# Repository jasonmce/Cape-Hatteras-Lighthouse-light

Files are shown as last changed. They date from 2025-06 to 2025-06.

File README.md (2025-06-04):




# 🗼 Cape Hatteras Lighthouse Light

This project recreates the iconic Cape Hatteras Lighthouse light as a 3D-printed model, complete with an Arduino-driven animation that mimics the real-world light signature of the actual lighthouse. At dusk a string of NeoPixels illuminate the lighthouse with a rotating beam effect - to help my sister park &#128515;.

It is an example of a solar-powered Lighthouse Light, with a weatherproof enclosure, a switch to turn it on and off, and a solar charge controller to keep the battery charged.  It is meant to be easy to extend for creating your own lighthouse light model and custom signature.

## 📚 Background
My sister asked for a Cape Hatteras lighthouse garden decoration for her birthday.  Making the body was a fun project, but illuminating it was the part that interested me.  It was a great experience in what could go wrong with distantly deployed deliverables.

Evolutions in this project:
- Upgraded to a **10K mAh battery** to survive multiple days of darkness
- Stronger housing.  I originally used [Thingiverse myst lighthouse](https://www.thingiverse.com/thing:3164021) as the light fixture but it proved brittle when:
    - branches hit it
    - wind toppled the structure
- Designed a custom light model to better match the Cape Hatteras light
- Added an external power switch to:
    - Reset the circuit if low voltage causes Arduino issues
    - Ensure a solid charge after prolonged darkness
---

## 🔧 Features

- Fully 3D printable model, designed in modular STL components.
- Arduino-compatible `.ino` sketch to drive a NeoPixel LED strip.
- Solar powered - no charging or replacing of batteries required.
- Detects when it is dark and animates the light.
- Mimics the actual flash pattern of Cape Hatteras Lighthouse (light every 7.5 seconds).
- Designed to house internal wiring and switch access.
  
---

## 🖨️ 3D Printed Parts

All STL files can be found [On Thingiverse](https://www.thingiverse.com/thing:7056934) and in the `models/` directory:

- `roof.stl` – Top cap for the lighthouse.
- `lens.stl` – Translucent lens for the light animation.
- `base.stl` – Base of the lighthouse.
- `base_ring_for_switch.stl` – Fits below base to allow switch access.
- `core.stl` – Internal lighthouse column that holds electronics.

---

## 🧠 Arduino Code

The `code/lighthouse.ino` sketch uses the Adafruit NeoPixel library to animate a light strip. It creates a rotating beam with fade transitions that align with the lighthouse's characteristic 7.5-second interval signature.

Requirements:
- Arduino Uno or compatible board - I used a Seeeduino XIAO because it was handy.
- Adafruit NeoPixel library
- 21 NeoPixel strip - can be customized to any length
- Light sensor
- Solar panel
- Weather proof switch
- Solar charge controller
- LiPo battery - Mine is a whopping 10K mAh to outlast a few dark or rainy days

---

## 🖼️ Photos

<figure>
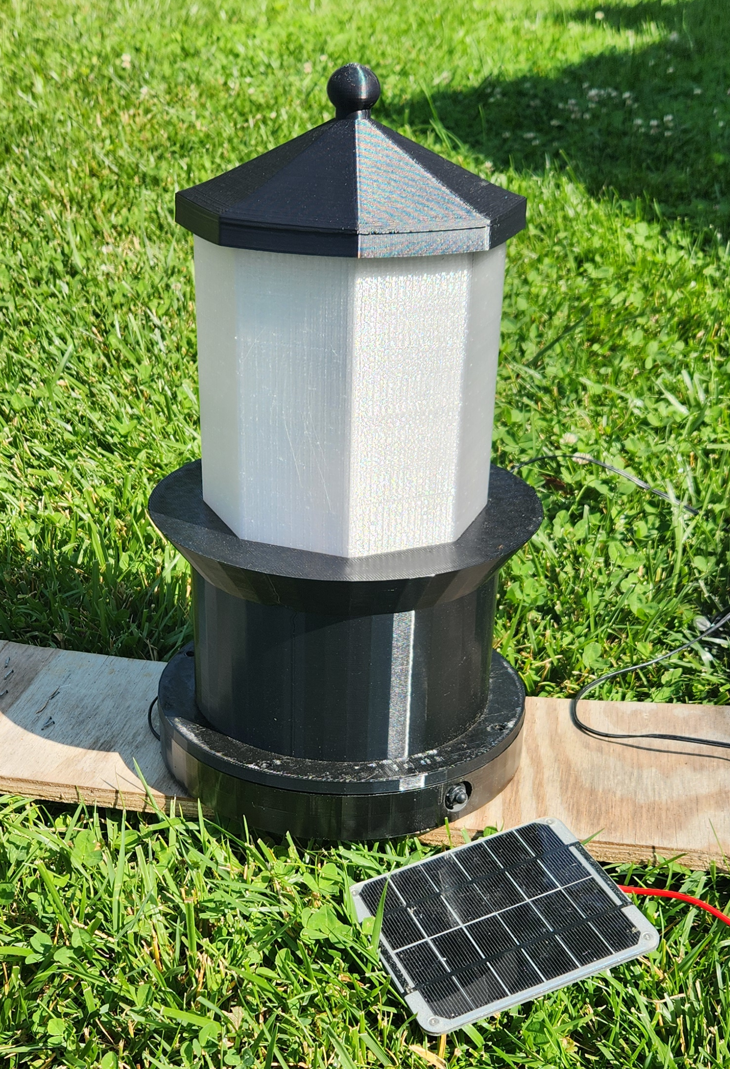
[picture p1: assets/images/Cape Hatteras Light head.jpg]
Assembled lighthouse with solar panel
    
    <figcaption><strong>Model Head</strong></figcaption>
</figure>
<figure>
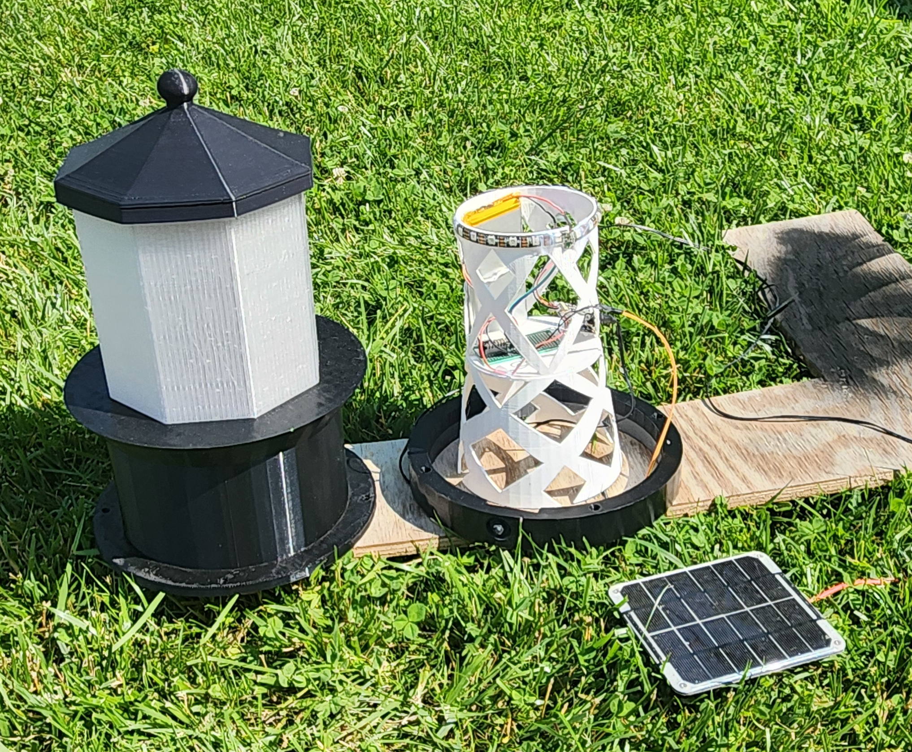
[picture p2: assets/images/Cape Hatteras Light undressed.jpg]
Lighthouse with electronics exposed
    
    <figcaption><strong>Undressed View</strong></figcaption>
</figure>
<figure>
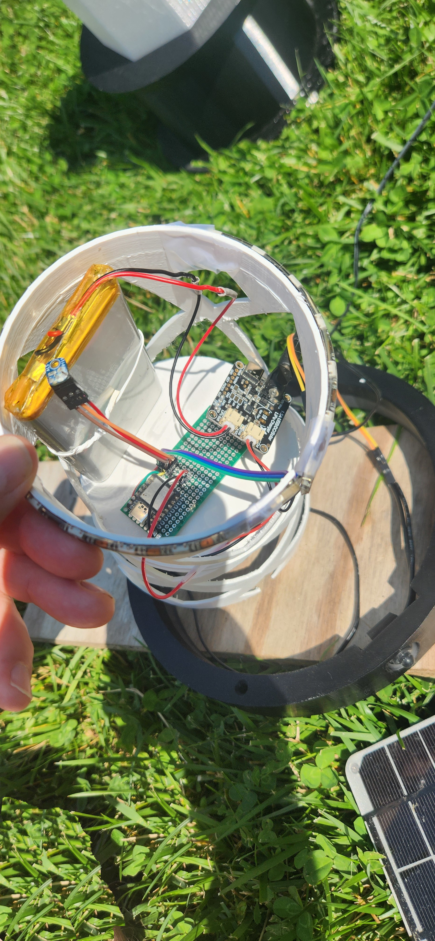
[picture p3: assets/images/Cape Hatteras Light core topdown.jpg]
Top down view of the core electronics
    
    <figcaption><strong>Core Top-down View</strong></figcaption>
</figure>

---

## ⚙️ Assembly Notes

- Print the lens using clear or translucent filament for best light diffusion.
- Attach the NeoPixel strip onto the core, aligned with the center of the lens.
- Connect the NeoPixel strip to 5V, GND, and a digital pin (e.g., D10) on your Arduino.
- Connect the light sensor to an analog pin (e.g., A9) on your Arduino.
- Use the `base_ring_for_switch.stl` if you want external access to the power or mode switch
    It will control the connection between the solar controller output and the Arduino.

---

## 🔧 Future Enhancements

The following features are under consideration to improve usability, reliability, and functionality:

- **Adjustable Darkness Threshold**  
  Integrate a rheostat to allow users to fine-tune the ambient light threshold that triggers the lighthouse light. This would offer greater flexibility across varying environments and seasons.

- **Improved NeoPixel Strip Mounting**  
  Add structural clips around the top of the core to provide secure, mechanical support for the NeoPixel strip. This will improve long-term durability and reduce dependence on adhesive backing.

- **Inspection Mode via Wi-Fi Access Point**  
  Introduce an "Inspection" button that temporarily enables a local Wi-Fi Access Point. When connected, users would be presented with an HTML interface displaying real-time sensor values, status indicators, and system diagnostics for troubleshooting and fine-tuning.
---

## 📜 License

MIT License. Use and remix freely, and credit is appreciated.

---

## 🗺️ About the Real Lighthouse

Cape Hatteras Lighthouse is located in North Carolina and is known for its distinct black-and-white spiral pattern and strong maritime heritage. The animation in this project replicates its 7.5-second rotating flash pattern.

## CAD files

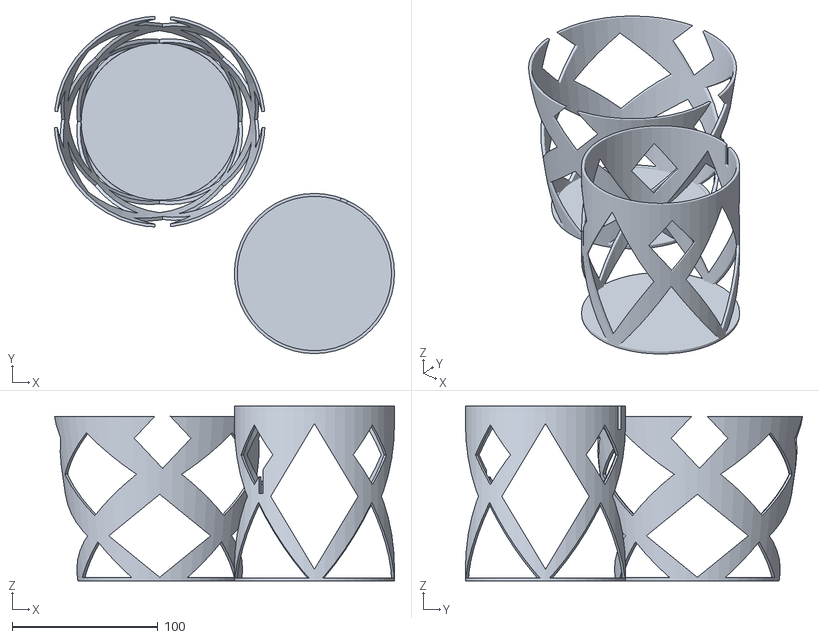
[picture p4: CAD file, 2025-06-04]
models/Cape Hatteras Light core.stl
233.5 x 231.6 x 120.0

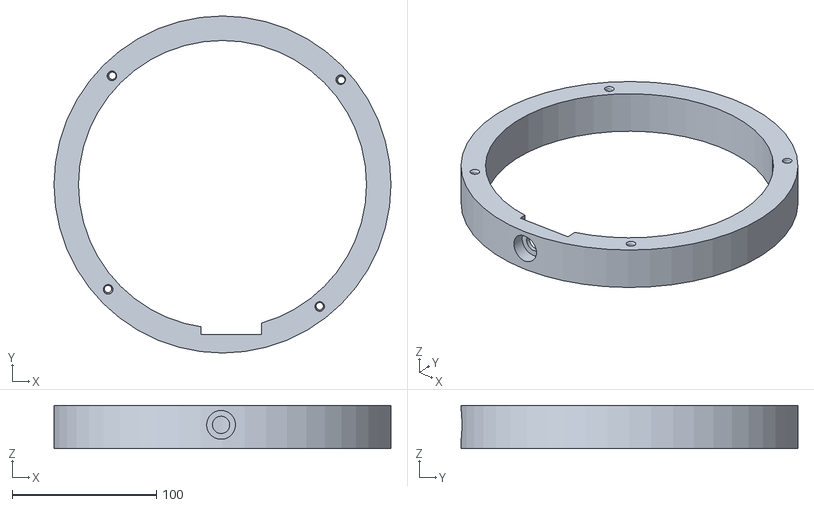
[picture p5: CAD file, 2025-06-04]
models/Cape Hatteras Light base ring for switch.stl
234.0 x 234.0 x 30.0

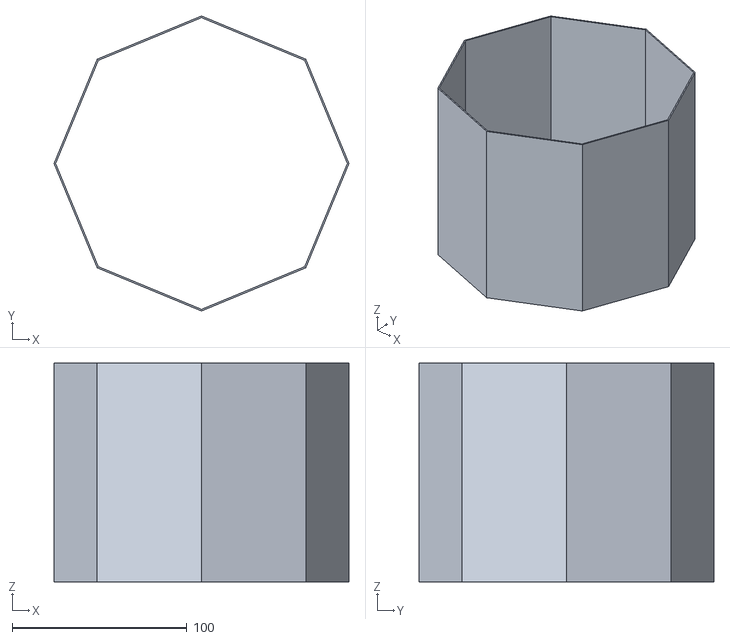
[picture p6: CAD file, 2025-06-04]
models/Cape Hatteras Light lens.stl
168.8 x 168.8 x 125.0

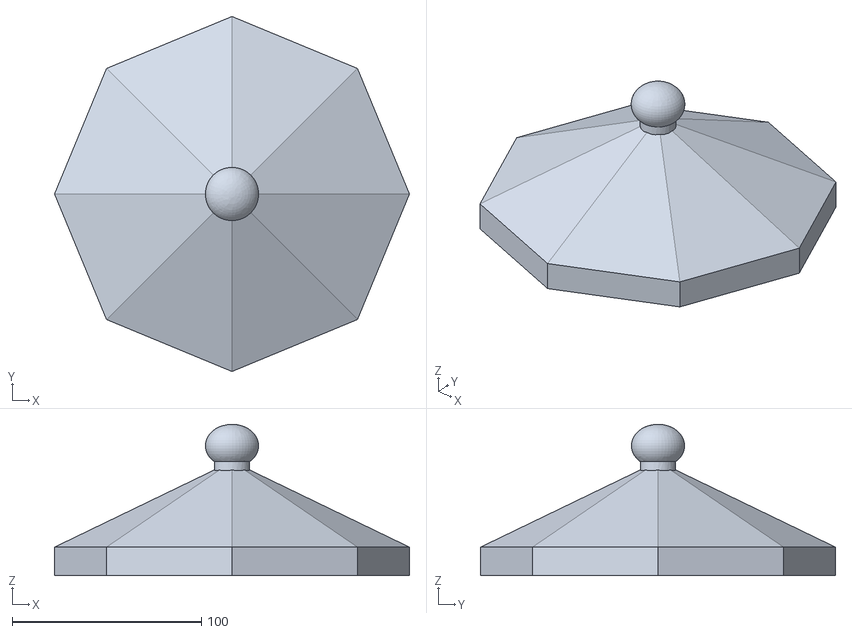
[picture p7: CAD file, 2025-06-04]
models/Cape Hatteras Light roof.stl
187.5 x 187.5 x 80.0

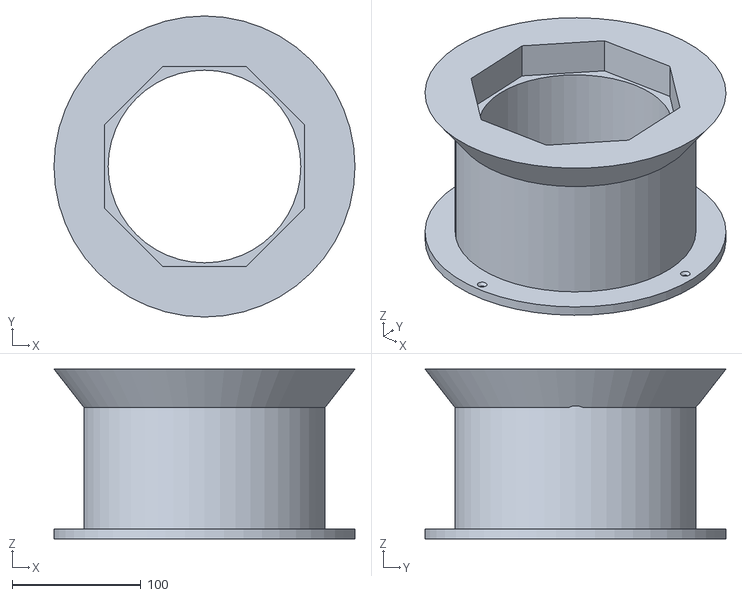
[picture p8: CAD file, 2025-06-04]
models/Cape Hatteras Light base.stl
234.0 x 234.0 x 132.0

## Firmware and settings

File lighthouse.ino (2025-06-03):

/**
Lighthouse

Made this to illuminate a Cape Hatteras garden lighthouse model I made
for my sister's birthday.

Originally run on a Seeeduino XIAO, because I had one lying around.

Animate a line of neopixels to look like a lighthouse light.
Scales 4 lights along the strand to simulate the "lens" rotating:
  trailing, main, next main, and leading.

Uses a light sensor determine when to animate.

Place light sensor on the opposite side of the strip start to avoid getting
erroneous ambient value from the lights.

The code periodically checks the ambient light sensor, and when darkness is
detected it starts a full light rotation.
*/

#include <Adafruit_NeoPixel.h>

// The two states are playing a full light rotation and waiting for darkness.
enum State {
  PlayingLightAnimation,
  AwaitingDarkness,
};
State currentState = State::AwaitingDarkness;


// Number of NeoPixels in our light loop.
#define PIXEL_COUNT 21

// Digital IO pin connected to the NeoPixels.
#define PIXEL_PIN 10

// Steps in a light increment per offset.
#define STEPS 40     

// Milliseoncds for one rotation of the light.
// Cape Hatteras lighthouse has a characteristic of one flash
// every 7.5 seconds.
#define PERIOD_MS 7500

// Delay between loops so that a full cycle takes PERIOD_MS.
#define DELAY_MS PERIOD_MS / (PIXEL_COUNT * STEPS)




// Digital IO pin connected to the light sensor.
#define LIGHT_SENSOR_PIN 9

// Ambient light below this percentage of sensor range starts the animation.
#define LIGHT_THRESHOLD 20

// Milliseconds delay between ambient light checks.
#define LIGHT_CHECK_DELAY 5000

Adafruit_NeoPixel strip = Adafruit_NeoPixel(PIXEL_COUNT, PIXEL_PIN, NEO_GRB + NEO_KHZ800);

// Light 
int mainLightIndex = 0;
int current_step = 0;

void setup() {
  Serial.begin(115200);
  strip.begin();
  turnOffLights();
}

void setLight(int offset, int step) {
  int pixel_index; 
  int brightness_shift;
  int brightness;
  uint32_t color;

  // Wrap if mainLightIndex plus offset is negative.
  pixel_index = (mainLightIndex + offset + PIXEL_COUNT) % PIXEL_COUNT;
  brightness_shift = step * (80 / STEPS);

  // Trailing light.
  if (offset < 0) {
    brightness = (80 * (2 + offset)) - brightness_shift;
  }
  // Main light.
  if (0 == offset) {
    brightness = 240 - brightness_shift;
  }
  // Next light and leading light.
  if (offset > 0) {
    brightness = (80 * (2 - offset)) + brightness_shift;
  }

  color = strip.Color(brightness, brightness, brightness);
  strip.setPixelColor(pixel_index, color);
}

void drawLights() {
  // Trailing light.
  setLight(-1, current_step);
  // Main light.
  setLight(0, current_step);
  // Next main light.
  setLight(1, current_step);
  // leading light.
  setLight(2, current_step);
  
  strip.show();
}

void incrementCounters() {
  current_step++;
  if (current_step > STEPS) {
    current_step = 0;
    mainLightIndex++;
  }
}

bool hasLightAnimationCompleted() {
  return mainLightIndex >= PIXEL_COUNT;
}

void resetCounters() {
  mainLightIndex = 0;
  current_step = 0;  
}

bool isDaylightOut() {
  int ambientLightPercent = analogRead(LIGHT_SENSOR_PIN) * ((float)100 / 1023.0);
  Serial.print("ambientLightPercent is ");
  Serial.println(ambientLightPercent);
  return ambientLightPercent > LIGHT_THRESHOLD;
}

void turnOffLights() {
  Serial.println("Turning off lights");
  strip.clear();
  strip.show();
}

void loop() {
  Serial.println("\n\nLoop");

  bool darkEnoughForLights = !isDaylightOut();

  Serial.print("Dark enough is ");
  Serial.println(darkEnoughForLights);

  // Still too bright to start.
  if (currentState == State::AwaitingDarkness && !darkEnoughForLights) {
    Serial.println("Still awaiting darkness");
    delay(LIGHT_CHECK_DELAY);
    return;
  }

  // It is now dark enough to start.
  if (currentState == State::AwaitingDarkness && darkEnoughForLights) {
    Serial.println("Switching to PlayingLightAnimation");
    currentState = State::PlayingLightAnimation;
  }

  bool lightAnimationCompleted = hasLightAnimationCompleted();

  // Continue the light animation
  if (currentState == State::PlayingLightAnimation && !lightAnimationCompleted) {
    Serial.println("Continue PlayingLightAnimation");

    Serial.print("mainLightIndex is ");
    Serial.print(mainLightIndex);

    Serial.print("  current_step is ");
    Serial.println(current_step);

    drawLights();
    incrementCounters();
    delay(DELAY_MS);
    return;
  }

  // Continue again from the beginning.
  if (currentState == State::PlayingLightAnimation && lightAnimationCompleted && darkEnoughForLights) {
    Serial.println("Loop PlayingLightAnimation");
    resetCounters();
    return;
  }

  // Turn off lights and change state.
  if (currentState == State::PlayingLightAnimation && lightAnimationCompleted && !darkEnoughForLights) {
    Serial.println("Switching to AwaitingDarkness");
    turnOffLights();
    resetCounters();
    currentState = State::AwaitingDarkness;
    return;
  }

}

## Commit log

2025-06-04 Add model files for printing
    [Cape Hatteras Light base ring for switch.stl, Cape Hatteras Light base.stl, Cape Hatteras Light core.stl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]
2025-06-04 Add a README file and associated assets someone else could use to make their own lighthouse light
    [Cape Hatteras Light base ring for switch.stl, Cape Hatteras Light base.stl, Cape Hatteras Light core.stl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]
2025-06-04 Include thingiverse link to the printable model
2025-06-04 Add a future enhancements section in case anyone wants to pitch in :)
